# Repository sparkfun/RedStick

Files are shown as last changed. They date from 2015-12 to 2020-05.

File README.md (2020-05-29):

**NOTE:** *This product has been retired from our catalog. If you are looking for more up-to-date info, please check out some of these resources to see how other users are still hacking and improving on this product.*
* *[SparkFun Forum](https://forum.sparkfun.com/)*
* *[Comments Here on GitHub](https://github.com/sparkfun/RedStick/issues)*

SparkFun RedStick
========================================

SparkFun RedStick

[*SparkFun RedStick (DEV-13741)*](https://www.sparkfun.com/products/13741)

A 328p micro board with boost regulator that runs at 16MHz and has a built in boost regulator for battery usage.

Spawned from the BadgerStick promo.

Repository Contents
-------------------

* **/Documentation** - Data sheets, additional product information
* **/Hardware** - Eagle design files (.brd, .sch)
* **/Production** - Production panel files (.brd)
* **/Software** - Related software for the RedStick

Documentation
--------------
* **[LED Array Library](https://github.com/sparkfun/SparkFun_LED_Array_8x7_Arduino_Library)** - Arduino LED Array library for the RedStick.
* **[Hookup Guide](https://learn.sparkfun.com/tutorials/redstick-hookup-guide)** - Basic hookup guide for the RedStick.
* **[SparkFun Fritzing repo](https://github.com/sparkfun/Fritzing_Parts)** - Fritzing diagrams for SparkFun products.
* **[SparkFun 3D Model repo](https://github.com/sparkfun/3D_Models)** - 3D models of SparkFun products. 

Version History
---------------
* [V_1.0](https://github.com/sparkfun/RedStick/tree/V_1.0) - Product release version

License Information
-------------------

This product is _**open source**_! 

Please review the LICENSE.md file for license information. 

If you have any questions or concerns on licensing, please contact techsupport@sparkfun.com.

Distributed as-is; no warranty is given.

- Your friends at SparkFun.

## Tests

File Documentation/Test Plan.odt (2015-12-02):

# Functional Testing Plan

## Functional Things to Verify

- Does the serial pinout make sense?

## HW Things to Verify

- Power consumption
- Sweep input voltage from 1 to max 6 V with low load
- Sweep input voltage from 1 to max 6 V with large load (100mA)
- Measure efficiency and 5v voltage/ripple/sag
- Test that the battery port is protected.
- Test that the boost is protected from serial power
- I2C signal integrity – Test with known board
- SPI signal integrity – Test with known board
- Serial port signal integrity – Test with known board
- GPIO rise time and ringing with no load – record

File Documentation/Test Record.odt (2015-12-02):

# Functional Test Record – SparkFun RedStick

Marshall Taylor

11/30/2015

HW version v01

## Verifying Serial Pinout

Procedure:

(note: Products that have TTL: FTDI basics, serial 7 segment, pi wedge)

List SparkFun Products with TTL serial port:

- FTDI basic
- Serial 7 segment
- Pi Wedge
- Serial LCD
- GPS modules

Criteria:

Do modern and useful serial ports line up properly more often then not? Discuss

No real standard exists. TX and RX are together on a lot, with various organizations of power and ground. The FTDI is the closest thing to standard but has extra pins. Going with any old 4 pin pattern really. This one allows reverse without shorting powers, but does let TXI drive ground.

## Power Circuitry Tests

#### Low Load Test

Procedure:

- Power from battery input with fine voltage supply.
- Increase input voltage from 1V to 6V. Measure Vin/Iin, Vout/Iout, ripple

Criteria:

- Does regulator provide clean output between 2.0 V and 5.0 V?
- Is efficiency above 80% in this range? No
- Is ripple below 10% in this range? Yes
- Mark the switching frequency: About 5kHz
- Data:

Ripple generated at low load (Burpy)

#### 100mA Load Test

Procedure:

- Load 100mA total, add load to VCC pin
- Power from battery input with fine voltage supply.
- Increase input voltage from 1V to 6V. Measure Vin/Iin, Vout/Iout, ripple

Criteria:

- Does regulator provide clean output between 2.0 V and 5.0 V? Yes
- Is efficiency above 80% in this range? No
- Is ripple below 10% in this range? Yes
- Mark the switching frequency: Various (See below)
- Data:

Ripple generated at 100mA

#### 200mA Load Test

Procedure:

- Load 200mA total, add load to VCC pin
- Power from battery input with fine voltage supply.
- Increase input voltage from 1V to 6V. Measure Vin/Iin, Vout/Iout, ripple

Criteria:

- Does regulator provide clean output between 2.0 V and 5.0 V? Voltage sags below 3.0 V, 4.0 V output at 2.5 V input
- Is efficiency above 80% in this range? No
- Is ripple below 10% in this range? Yes
- Mark the switching frequency: Various (See below)
- Data:

#### All Power Test Graphs

#### Test the regulator's reverse flow

Procedure:

- Apply 5.0 V to the serial VCC port
- Switch between shorting and opening the USB connection (simulate reverse plug-in)

Criteria:

- The total current input should match the no-load consumption of the MPU +/- 5% Shorting the USB power lines had zero effect on current draw.

#### Test the battery protection from rogue VCC input

Procedure:

- Attach a 3.0 V battery and current meter to the battery input.
- Apply 5.0 V to the serial VCC port.

Criteria:

- The battery must not accept current. The battery consumed 0.00 A

#### Test the battery protection from USB input

Procedure:

- Attach a 3.0 V battery and current meter to the battery input
- Apply 5.0 V to the USB VCC port

Criteria:

- The battery must not accept current. The battery consumed 0.00 A

#### Extra test: Step loads

Procedure:

- Apply 2.5 V to the battery port
- Step loads between 0 and 100mA (total)

Criteria:

- Ringing should be minimal. 10 V for 40 ns
- Attach labeled scope captures.

38mA load switching in

75mA load switching in

75mA load switching out

95mA load switching in

95mA load switching out

#### Extra test: Reverse battery voltage

Procedure:

- Apply reverse voltage to battery terminals

Criteria:

- Must not crater. 0.00 A was consumed from the reverse voltage. RedStick operated normally afterwards.

## Set LED bias

Procedure:

- Measure red current at Vin = 2.0 V. 0.34mA
- Measure red current at Vin = 5.5 V. 0.36mA
- Measure green current at Vin = 2.0 V. 8.73mA
- Choose and set new resistors:
- Red: Use 4.7kOhm
- Green: Use 2.2kOhm for ~1.5mA of current

## Test I2C signal integrity

Procedure:

- Attach a I2C device and start communication
- Capture signals with a scope.

Criteria:

- Mark test device (AUT): 7segment display with 4.7kOhm pullups
- Are signals square and settled before clk edge?
- Clock should be clean
- Record scope capture

## Test SPI signal integrity

Procedure:

- Attach a SPI device through level shifter and start communication
- Capture signals with a scope between EUT and level shifter

Criteria:

- Mark test defice (AUT): BME280 with level shifter
- Are signals square and settled before clk edge?
- Clock should be clean
- Record scope capture

## Test serial TTL signal integrity

Procedure:

- Attach a serial device and start communication
- Capture signals with a scope.

Criteria:

- Mark test defice (AUT): FTDI loop at 115200 baud
- Are RX and TX typical?: Yes
- Record scope capture

TXO

RXI

## Test GPIO

Procedure:

- Set code to pulse each pin sequentially
- Capture signals with a scope.
- Look for out of order pulses ( > 1 pulse per pin13 cycle)
- Verify A0 – A7 by translating inputs to a PWM output and measuring

Criteria:

- Is each pin individually controllable? Yes
- Do any pins stick out as different from the others? No
- Do all analog inputs work and are stable? Yes
- Record scope capture of worst 2 pins. All pretty much the same

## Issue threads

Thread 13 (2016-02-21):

Incorrect part value

BrentWilkins, 2016-02-21:
The FTS31... Should be a FT231X...

ToniCorinne, 2016-03-07:
As this change will update the IC silk, leaving as-is until a revision is needed.

SFEMark, 2020-05-29:
Retired product. Closing issue.

bboyho, 2020-05-29:
In case anyone was wondering, this looks like it was just the part name in the schematic and it did not require changes to the silkscreen in the board file.

Closed 2020-05-29.

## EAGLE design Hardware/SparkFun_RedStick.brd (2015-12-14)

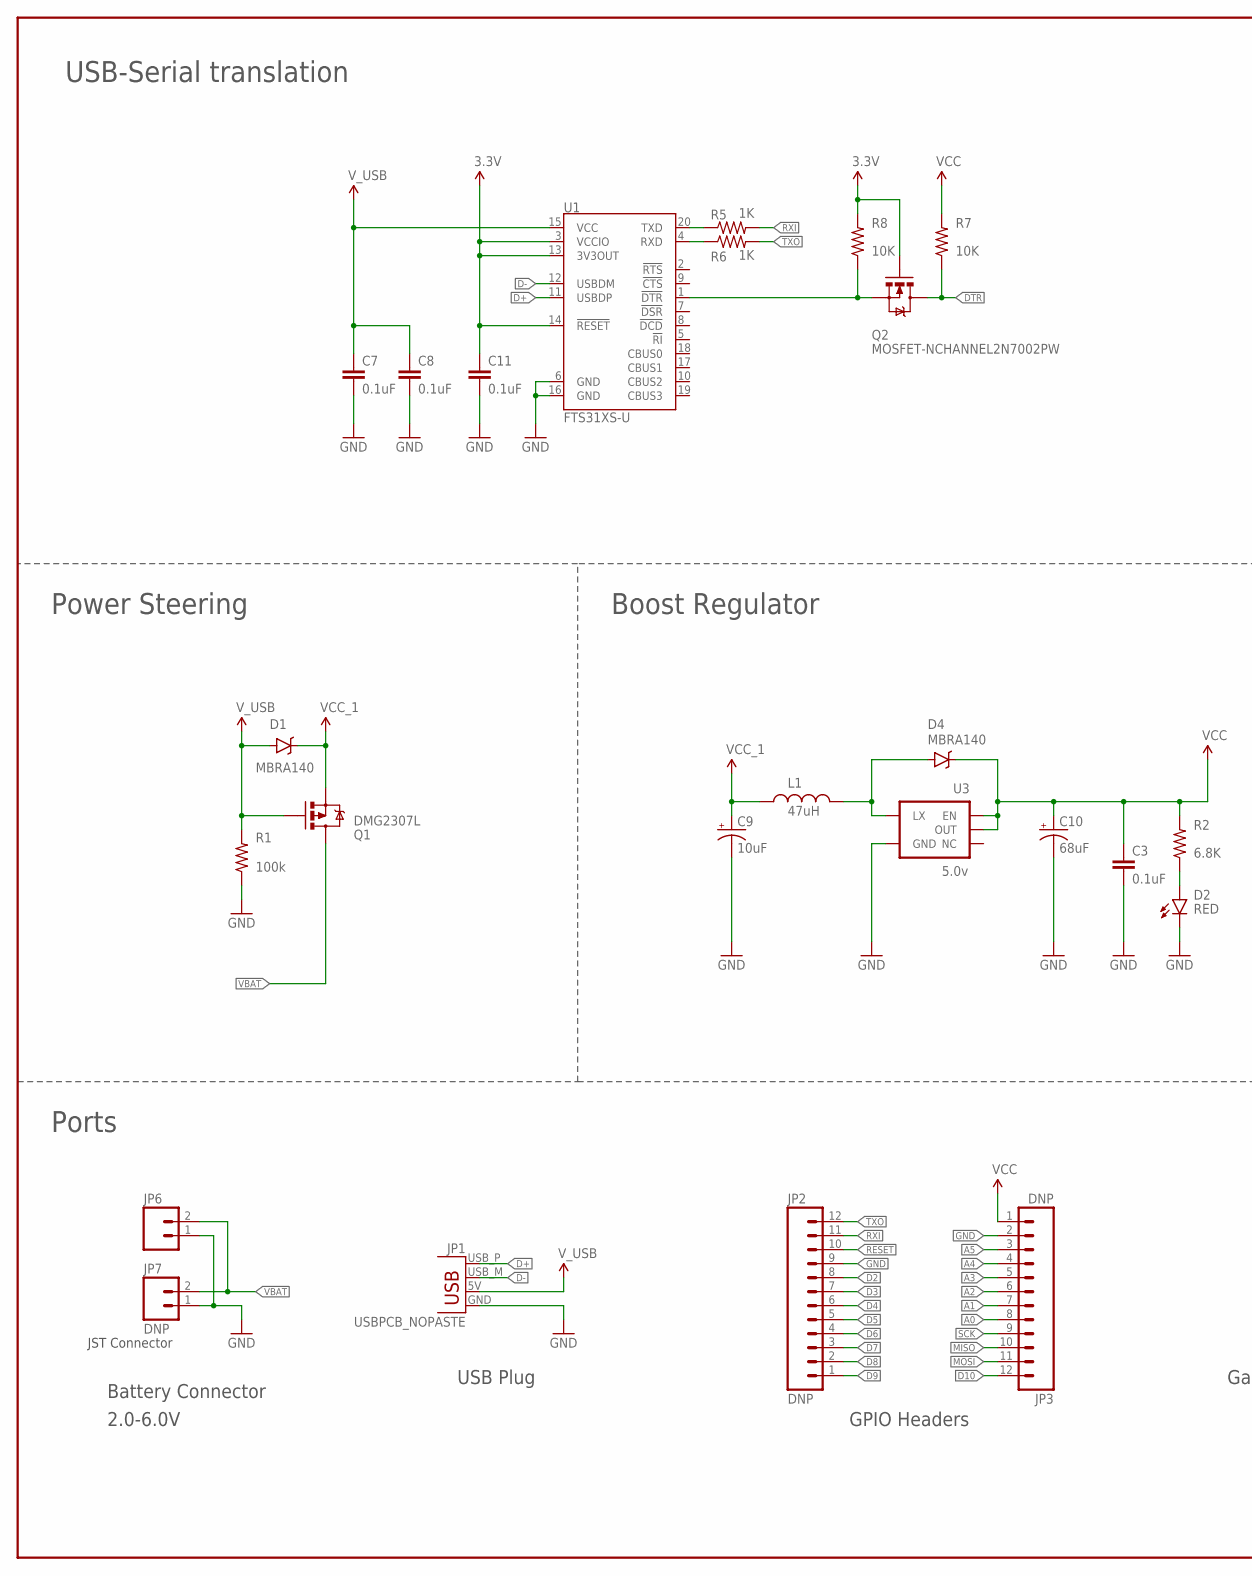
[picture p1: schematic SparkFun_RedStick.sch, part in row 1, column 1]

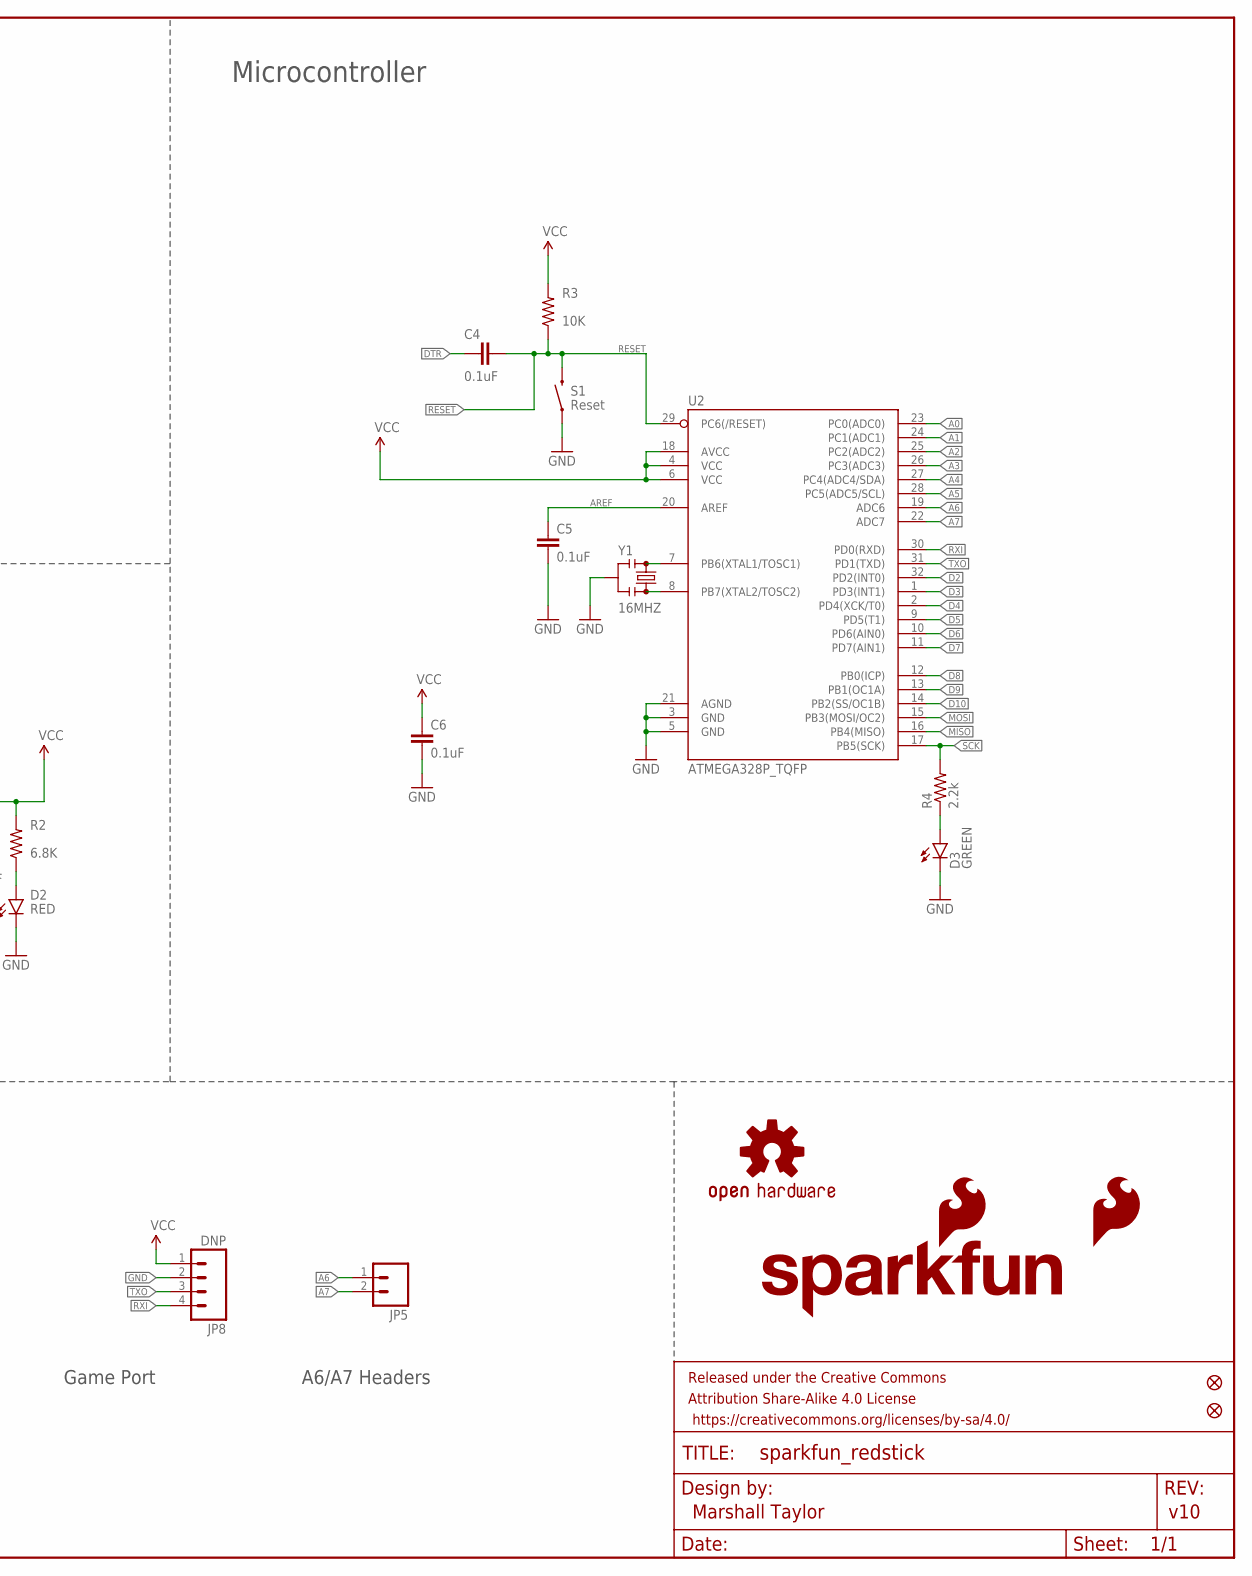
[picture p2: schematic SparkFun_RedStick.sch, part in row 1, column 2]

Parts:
C3, C4, C5, C6, C7, C8, C11: 0.1uF; 0603-CAP
C9: 10uF; EIA3216
C10: 68uF; EIA3528
D1, D4: MBRA140; SMA-DIODE
D2: RED; LED-0603
D3: GREEN; LED-0603
FID1, FID2: FIDUCIAL1X2; FIDUCIAL-1X2
FRAME2: FRAME-LEDGER; CREATIVE_COMMONS
JP1: USBPCB_NOPASTE; USB-A-PCB-NOPASTE
JP2, JP3: DNP; 1X12_NO_SILK
JP5, JP6: M021X02_NO_SILK; 1X02_NO_SILK
JP7: DNP; JST-2-PTH
JP8: DNP; 1X04_NO_SILK_ALL_ROUND
L1: 47uH; CR54
LOGO1: SFE_LOGO_FLAME.1_INCH; SFE_LOGO_FLAME_.1
LOGO2: OSHW-LOGOS; OSHW-LOGO-S
Q1: DMG2307L; SOT23-3
Q2: MOSFET-NCHANNEL2N7002PW; SOT323
R1: 100k; 0603-RES
R2: 6.8K; 0603-RES
R3, R7, R8: 10K; 0603-RES
R4: 2.2k; 0603-RES
R5, R6: 1K; 0603-RES
S1: SWITCH-MOMENTARY-2SMD-REDUNDANT; TACTILE-SWITCH-SMD
U1: FTS31XS-U; SSOP20_L
U2: ATMEGA328P_TQFP; TQFP32-08
U3: 5.0v; SOT23-5
U$1: SFE_LOGO_NAME_FLAME.1_INCH; SFE_LOGO_NAME_FLAME_.1
Y1: 16MHZ; RESONATOR-SMD

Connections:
3.3V: C11.1, Q2.1 (G), R8.2, U1.3 (VCCIO), U1.13 (3V3OUT), U1.14 (!RESET)
A0: JP3.8, U2.23 (PC0(ADC0))
A1: JP3.7, U2.24 (PC1(ADC1))
A2: JP3.6, U2.25 (PC2(ADC2))
A3: JP3.5, U2.26 (PC3(ADC3))
A4: JP3.4, U2.27 (PC4(ADC4/SDA))
A5: JP3.3, U2.28 (PC5(ADC5/SCL))
A6: JP5.1, U2.19 (ADC6)
A7: JP5.2, U2.22 (ADC7)
AREF: C5.1, U2.20 (AREF)
D2: JP2.8, U2.32 (PD2(INT0))
D3: JP2.7, U2.1 (PD3(INT1))
D4: JP2.6, U2.2 (PD4(XCK/T0))
D5: JP2.5, U2.9 (PD5(T1))
D6: JP2.4, U2.10 (PD6(AIN0))
D7: JP2.3, U2.11 (PD7(AIN1))
D8: JP2.2, U2.12 (PB0(ICP))
D9: JP2.1, U2.13 (PB1(OC1A))
D10: JP3.12, U2.14 (PB2(SS/OC1B))
D+: JP1.USB_P (D+), U1.11 (USBDP)
D-: JP1.USB_M (D-), U1.12 (USBDM)
DTR: C4.1, Q2.3 (D), R7.1
GND: C3.2, C5.2, C6.2, C7.2, C8.2, C9.C (-), C10.C (-), C11.2, D2.C, D3.C, JP1.GND, JP2.9, JP3.2, JP6.1, JP7.1, JP8.2, R1.1, S1.1, S1.2 (1), U1.6 (GND), U1.16 (GND), U2.3 (GND), U2.5 (GND), U2.21 (AGND), U3.4 (GND), Y1.2
MISO: JP3.10, U2.16 (PB4(MISO))
MOSI: JP3.11, U2.15 (PB3(MOSI/OC2))
unnamed: D3.A, R4.1
unnamed: R5.1, U1.20 (TXD)
unnamed: D2.A, R2.1
unnamed: U2.7 (PB6(XTAL1/TOSC1)), Y1.1
unnamed: U2.8 (PB7(XTAL2/TOSC2)), Y1.3
unnamed: R6.1, U1.4 (RXD)
unnamed: D4.A, L1.P$2 (2), U3.5 (LX)
unnamed: Q2.2 (S), R8.1, U1.1 (!DTR)
RESET: C4.2, JP2.10, R3.1, S1.3 (2), S1.4 (2), U2.29 (PC6(/RESET))
RXI: JP2.11, JP8.4, R5.2, U2.30 (PD0(RXD))
SCK: JP3.9, R4.2, U2.17 (PB5(SCK))
TXO: JP2.12, JP8.3, R6.2, U2.31 (PD1(TXD))
VBAT: JP6.2, JP7.2, Q1.3 (D)
VCC: C3.1, C6.1, C10.A (+), D4.C, JP3.1, JP8.1, R2.2, R3.2, R7.2, U2.4 (VCC), U2.6 (VCC), U2.18 (AVCC), U3.1 (EN), U3.2 (OUT)
VCC_1: C9.A (+), D1.C, L1.P$1 (1), Q1.2 (S)
V_USB: C7.1, C8.1, D1.A, JP1.5V (VBUS), Q1.1 (G), R1.2, U1.15 (VCC)

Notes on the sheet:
USB Plug
GPIO Headers
A6/A7 Headers
Game Port
Battery Connector
JST Connector
Ports
Power Steering
Boost Regulator
USB-Serial translation
Microcontroller
v10
Marshall Taylor
2.0-6.0V

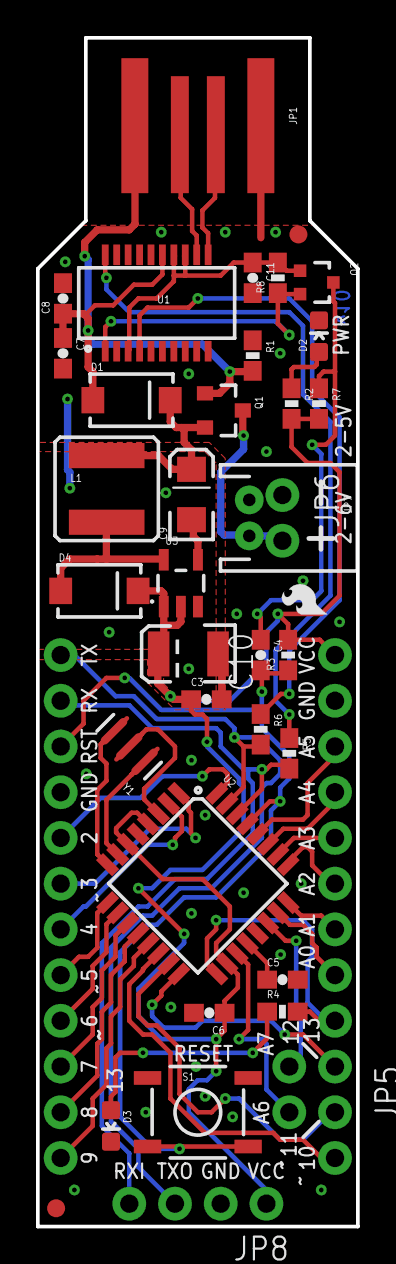
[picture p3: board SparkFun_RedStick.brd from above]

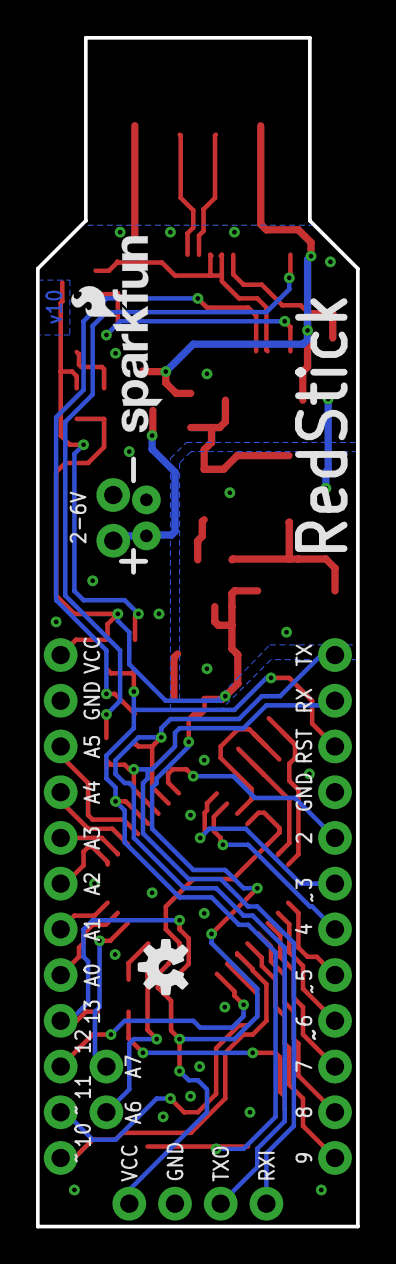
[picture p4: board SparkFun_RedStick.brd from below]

Board: 2 copper layers, 17.8 x 66.0 mm, 42 parts (2 on the bottom side), 41 nets.

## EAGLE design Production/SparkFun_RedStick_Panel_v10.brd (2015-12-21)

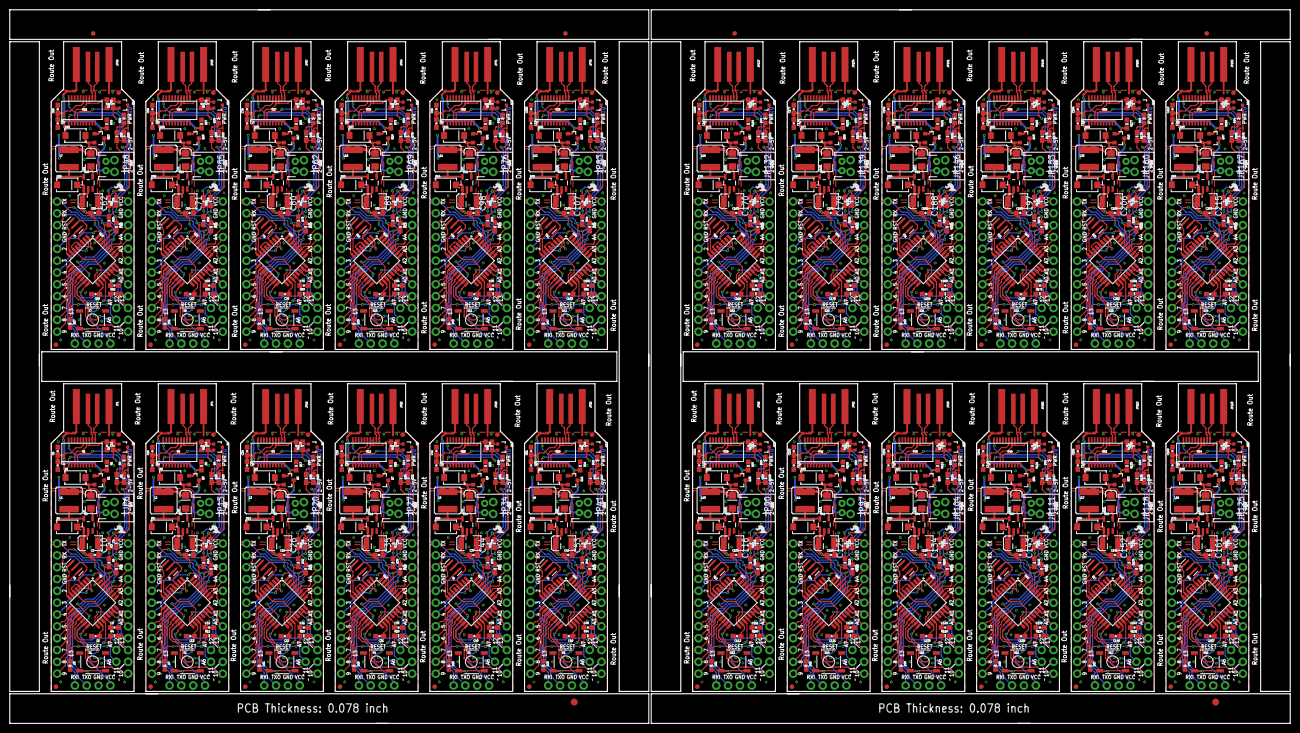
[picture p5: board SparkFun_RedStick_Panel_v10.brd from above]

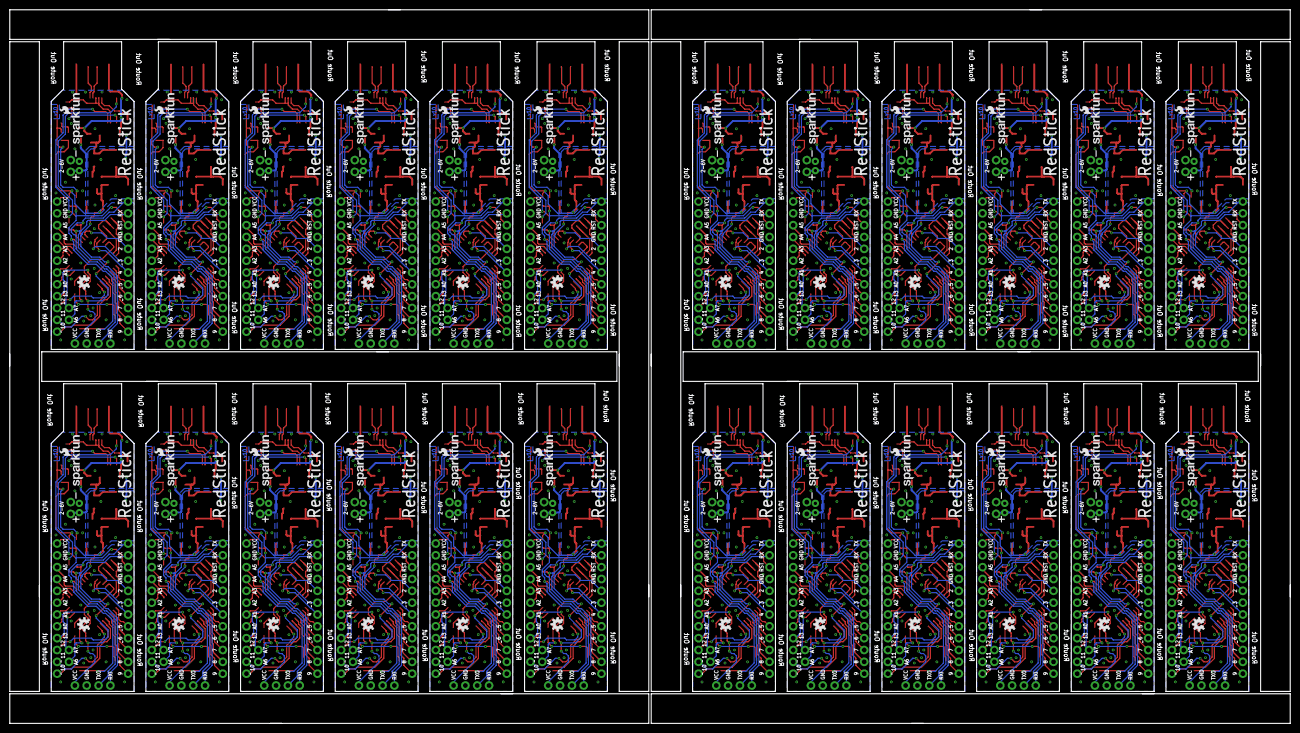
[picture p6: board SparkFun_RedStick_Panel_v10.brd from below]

Board: 2 copper layers, 274.8 x 153.2 mm, 990 parts (48 on the bottom side), 984 nets.

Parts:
C1, C2, C3, C4, C5, C6, C7, C8, C11, C12, C13, C14, C15, C18, C19, C20, C21, C22, C23, C24, C27, C28, C29, C30, C31, C32, C33, C36, C37, C38, C39, C40, C41, C42, C45, C46, C47, C48, C49, C50, C51, C54, C55, C56, C57, C58, C59, C60, C63, C64, C65, C66, C67, C68, C69, C72, C73, C74, C75, C76, C77, C78, C81, C82, C83, C84, C85, C86, C87, C90, C91, C92, C93, C94, C95, C96, C99, C100, C101, C102, C103, C104, C105, C108, C109, C110, C111, C112, C113, C114, C117, C118, C119, C120, C121, C122, C123, C126, C127, C128, C129, C130, C131, C132, C135, C136, C137, C138, C139, C140, C141, C144, C145, C146, C147, C148, C149, C150, C153, C154, C155, C156, C157, C158, C159, C162, C163, C164, C165, C166, C167, C168, C171, C172, C173, C174, C175, C176, C177, C180, C181, C182, C183, C184, C185, C186, C189, C190, C191, C192, C193, C194, C195, C198, C199, C200, C201, C202, C203, C204, C207, C208, C209, C210, C211, C212, C213, C216: 0.1uF; 0603-CAP
C9, C16, C25, C34, C43, C52, C61, C70, C79, C88, C97, C106, C115, C124, C133, C142, C151, C160, C169, C178, C187, C196, C205, C214: 10uF; EIA3216
C10, C17, C26, C35, C44, C53, C62, C71, C80, C89, C98, C107, C116, C125, C134, C143, C152, C161, C170, C179, C188, C197, C206, C215: 68uF; EIA3528
D1, D4, D5, D8, D9, D12, D13, D16, D17, D20, D21, D24, D25, D28, D29, D32, D33, D36, D37, D40, D41, D44, D45, D48, D49, D52, D53, D56, D57, D60, D61, D64, D65, D68, D69, D72, D73, D76, D77, D80, D81, D84, D85, D88, D89, D92, D93, D96: MBRA140; SMA-DIODE
D2, D6, D10, D14, D18, D22, D26, D30, D34, D38, D42, D46, D50, D54, D58, D62, D66, D70, D74, D78, D82, D86, D90, D94: RED; LED-0603
D3, D7, D11, D15, D19, D23, D27, D31, D35, D39, D43, D47, D51, D55, D59, D63, D67, D71, D75, D79, D83, D87, D91, D95: GREEN; LED-0603
E$1, E$4: FIDUCIAL-1.5X3
E$2, E$3, E$5, E$6: FIDUCIAL-1X2
FID1, FID2, FID3, FID4, FID5, FID6, FID7, FID8, FID9, FID10, FID11, FID12, FID13, FID14, FID15, FID16, FID17, FID18, FID19, FID20, FID21, FID22, FID23, FID24, FID25, FID26, FID27, FID28, FID29, FID30, FID31, FID32, FID33, FID34, FID35, FID36, FID37, FID38, FID39, FID40, FID41, FID42, FID43, FID44, FID45, FID46, FID47, FID48: FIDUCIAL1X2; FIDUCIAL-1X2
JP1, JP4, JP15, JP22, JP29, JP36, JP43, JP50, JP57, JP64, JP71, JP78, JP85, JP92, JP99, JP106, JP113, JP120, JP127, JP134, JP141, JP148, JP155, JP162: USBPCB_NOPASTE; USB-A-PCB-NOPASTE
JP2, JP3, JP10, JP11, JP17, JP18, JP24, JP25, JP31, JP32, JP38, JP39, JP45, JP46, JP52, JP53, JP59, JP60, JP66, JP67, JP73, JP74, JP80, JP81, JP87, JP88, JP94, JP95, JP101, JP102, JP108, JP109, JP115, JP116, JP122, JP123, JP129, JP130, JP136, JP137, JP143, JP144, JP150, JP151, JP157, JP158, JP164, JP165: DNP; 1X12_NO_SILK
JP5, JP6, JP9, JP13, JP16, JP20, JP23, JP27, JP30, JP34, JP37, JP41, JP44, JP48, JP51, JP55, JP58, JP62, JP65, JP69, JP72, JP76, JP79, JP83, JP86, JP90, JP93, JP97, JP100, JP104, JP107, JP111, JP114, JP118, JP121, JP125, JP128, JP132, JP135, JP139, JP142, JP146, JP149, JP153, JP156, JP160, JP163, JP167: M021X02_NO_SILK; 1X02_NO_SILK
JP7, JP12, JP19, JP26, JP33, JP40, JP47, JP54, JP61, JP68, JP75, JP82, JP89, JP96, JP103, JP110, JP117, JP124, JP131, JP138, JP145, JP152, JP159, JP166: DNP; JST-2-PTH
JP8, JP14, JP21, JP28, JP35, JP42, JP49, JP56, JP63, JP70, JP77, JP84, JP91, JP98, JP105, JP112, JP119, JP126, JP133, JP140, JP147, JP154, JP161, JP168: DNP; 1X04_NO_SILK_ALL_ROUND
L1, L2, L3, L4, L5, L6, L7, L8, L9, L10, L11, L12, L13, L14, L15, L16, L17, L18, L19, L20, L21, L22, L23, L24: 47uH; CR54
LOGO1, LOGO3, LOGO5, LOGO7, LOGO9, LOGO11, LOGO13, LOGO15, LOGO17, LOGO19, LOGO21, LOGO23, LOGO25, LOGO27, LOGO29, LOGO31, LOGO33, LOGO35, LOGO37, LOGO39, LOGO41, LOGO43, LOGO45, LOGO47: SFE_LOGO_FLAME.1_INCH; SFE_LOGO_FLAME_.1
LOGO2, LOGO4, LOGO6, LOGO8, LOGO10, LOGO12, LOGO14, LOGO16, LOGO18, LOGO20, LOGO22, LOGO24, LOGO26, LOGO28, LOGO30, LOGO32, LOGO34, LOGO36, LOGO38, LOGO40, LOGO42, LOGO44, LOGO46, LOGO48: OSHW-LOGOS; OSHW-LOGO-S
Q1, Q3, Q5, Q7, Q9, Q11, Q13, Q15, Q17, Q19, Q21, Q23, Q25, Q27, Q29, Q31, Q33, Q35, Q37, Q39, Q41, Q43, Q45, Q47: DMG2307L; SOT23-3
Q2, Q4, Q6, Q8, Q10, Q12, Q14, Q16, Q18, Q20, Q22, Q24, Q26, Q28, Q30, Q32, Q34, Q36, Q38, Q40, Q42, Q44, Q46, Q48: MOSFET-NCHANNEL2N7002PW; SOT323
R1, R9, R17, R25, R33, R41, R49, R57, R65, R73, R81, R89, R97, R105, R113, R121, R129, R137, R145, R153, R161, R169, R177, R185: 100k; 0603-RES
R2, R10, R18, R26, R34, R42, R50, R58, R66, R74, R82, R90, R98, R106, R114, R122, R130, R138, R146, R154, R162, R170, R178, R186: 6.8K; 0603-RES
R3, R7, R8, R11, R15, R16, R19, R23, R24, R27, R31, R32, R35, R39, R40, R43, R47, R48, R51, R55, R56, R59, R63, R64, R67, R71, R72, R75, R79, R80, R83, R87, R88, R91, R95, R96, R99, R103, R104, R107, R111, R112, R115, R119, R120, R123, R127, R128, R131, R135, R136, R139, R143, R144, R147, R151, R152, R155, R159, R160, R163, R167, R168, R171, R175, R176, R179, R183, R184, R187, R191, R192: 10K; 0603-RES
R4, R12, R20, R28, R36, R44, R52, R60, R68, R76, R84, R92, R100, R108, R116, R124, R132, R140, R148, R156, R164, R172, R180, R188: 2.2k; 0603-RES
R5, R6, R13, R14, R21, R22, R29, R30, R37, R38, R45, R46, R53, R54, R61, R62, R69, R70, R77, R78, R85, R86, R93, R94, R101, R102, R109, R110, R117, R118, R125, R126, R133, R134, R141, R142, R149, R150, R157, R158, R165, R166, R173, R174, R181, R182, R189, R190: 1K; 0603-RES
S1, S2, S3, S4, S5, S6, S7, S8, S9, S10, S11, S12, S13, S14, S15, S16, S17, S18, S19, S20, S21, S22, S23, S24: SWITCH-MOMENTARY-2SMD-REDUNDANT; TACTILE-SWITCH-SMD
U1, U6, U9, U12, U15, U18, U21, U24, U27, U30, U33, U36, U39, U42, U45, U48, U51, U54, U57, U60, U63, U66, U69, U72: FTS31XS-U; SSOP20_L
U2, U4, U7, U10, U13, U16, U19, U22, U25, U28, U31, U34, U37, U40, U43, U46, U49, U52, U55, U58, U61, U64, U67, U70: ATMEGA328P_TQFP; TQFP32-08
U3, U5, U8, U11, U14, U17, U20, U23, U26, U29, U32, U35, U38, U41, U44, U47, U50, U53, U56, U59, U62, U65, U68, U71: 5.0v; SOT23-5
U$1, U$2, U$3, U$4, U$5, U$6, U$7, U$8, U$9, U$10, U$11, U$12, U$13, U$14, U$15, U$16, U$17, U$18, U$19, U$20, U$21, U$22, U$23, U$24: SFE_LOGO_NAME_FLAME.1_INCH; SFE_LOGO_NAME_FLAME_.1
Y1, Y2, Y3, Y4, Y5, Y6, Y7, Y8, Y9, Y10, Y11, Y12, Y13, Y14, Y15, Y16, Y17, Y18, Y19, Y20, Y21, Y22, Y23, Y24: 16MHZ; RESONATOR-SMD

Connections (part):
3.3V: C11.1, Q2.1, R8.2, U1.3, U1.13, U1.14
3.3V1: C18.1, Q4.1, R16.2, U6.3, U6.13, U6.14
3.3V2: C27.1, Q6.1, R24.2, U9.3, U9.13, U9.14
3.3V3: C36.1, Q8.1, R32.2, U12.3, U12.13, U12.14
3.3V4: C45.1, Q10.1, R40.2, U15.3, U15.13, U15.14
3.3V5: C54.1, Q12.1, R48.2, U18.3, U18.13, U18.14
3.3V6: C63.1, Q14.1, R56.2, U21.3, U21.13, U21.14
3.3V7: C72.1, Q16.1, R64.2, U24.3, U24.13, U24.14
3.3V8: C81.1, Q18.1, R72.2, U27.3, U27.13, U27.14
3.3V9: C90.1, Q20.1, R80.2, U30.3, U30.13, U30.14
3.3V10: C99.1, Q22.1, R88.2, U33.3, U33.13, U33.14
3.3V11: C108.1, Q24.1, R96.2, U36.3, U36.13, U36.14
3.3V12: C117.1, Q26.1, R104.2, U39.3, U39.13, U39.14
3.3V13: C126.1, Q28.1, R112.2, U42.3, U42.13, U42.14
3.3V14: C135.1, Q30.1, R120.2, U45.3, U45.13, U45.14
3.3V15: C144.1, Q32.1, R128.2, U48.3, U48.13, U48.14
3.3V16: C153.1, Q34.1, R136.2, U51.3, U51.13, U51.14
3.3V17: C162.1, Q36.1, R144.2, U54.3, U54.13, U54.14
3.3V18: C171.1, Q38.1, R152.2, U57.3, U57.13, U57.14
3.3V19: C180.1, Q40.1, R160.2, U60.3, U60.13, U60.14
3.3V20: C189.1, Q42.1, R168.2, U63.3, U63.13, U63.14
3.3V21: C198.1, Q44.1, R176.2, U66.3, U66.13, U66.14
3.3V22: C207.1, Q46.1, R184.2, U69.3, U69.13, U69.14
3.3V23: C216.1, Q48.1, R192.2, U72.3, U72.13, U72.14
A0: JP3.8, U2.23
A1: JP3.7, U2.24
A2: JP3.6, U2.25
A3: JP3.5, U2.26
A4: JP3.4, U2.27
A5: JP3.3, U2.28
A6: JP5.1, U2.19
A7: JP5.2, U2.22
A8: JP10.8, U4.23
A9: JP10.7, U4.24
A10: JP10.6, U4.25
A11: JP10.5, U4.26
A12: JP10.4, U4.27
A13: JP10.3, U4.28
A14: JP9.1, U4.19
A15: JP9.2, U4.22
A16: JP17.8, U7.23
A17: JP17.7, U7.24
A18: JP17.6, U7.25
A19: JP17.5, U7.26
A20: JP17.4, U7.27
A21: JP17.3, U7.28
A22: JP16.1, U7.19
A23: JP16.2, U7.22
A24: JP24.8, U10.23
A25: JP24.7, U10.24
A26: JP24.6, U10.25
A27: JP24.5, U10.26
A28: JP24.4, U10.27
A29: JP24.3, U10.28
A30: JP23.1, U10.19
A31: JP23.2, U10.22
A32: JP31.8, U13.23
A33: JP31.7, U13.24
A34: JP31.6, U13.25
A35: JP31.5, U13.26
A36: JP31.4, U13.27
A37: JP31.3, U13.28
A38: JP30.1, U13.19
A39: JP30.2, U13.22
A40: JP38.8, U16.23
A41: JP38.7, U16.24
A42: JP38.6, U16.25
A43: JP38.5, U16.26
A44: JP38.4, U16.27
A45: JP38.3, U16.28
A46: JP37.1, U16.19
A47: JP37.2, U16.22
A48: JP45.8, U19.23
A49: JP45.7, U19.24
A50: JP45.6, U19.25
A51: JP45.5, U19.26
A52: JP45.4, U19.27
A53: JP45.3, U19.28
A54: JP44.1, U19.19
A55: JP44.2, U19.22
A56: JP52.8, U22.23
A57: JP52.7, U22.24
A58: JP52.6, U22.25
A59: JP52.5, U22.26
A60: JP52.4, U22.27
A61: JP52.3, U22.28
A62: JP51.1, U22.19
A63: JP51.2, U22.22
A64: JP59.8, U25.23
A65: JP59.7, U25.24
A66: JP59.6, U25.25
A67: JP59.5, U25.26
A68: JP59.4, U25.27
A69: JP59.3, U25.28
A70: JP58.1, U25.19
A71: JP58.2, U25.22
A72: JP66.8, U28.23
A73: JP66.7, U28.24
A74: JP66.6, U28.25
A75: JP66.5, U28.26
A76: JP66.4, U28.27
A77: JP66.3, U28.28
A78: JP65.1, U28.19
A79: JP65.2, U28.22
A80: JP73.8, U31.23
A81: JP73.7, U31.24
A82: JP73.6, U31.25
A83: JP73.5, U31.26
A84: JP73.4, U31.27
A85: JP73.3, U31.28
A86: JP72.1, U31.19
A87: JP72.2, U31.22
A88: JP80.8, U34.23
A89: JP80.7, U34.24
A90: JP80.6, U34.25
A91: JP80.5, U34.26
A92: JP80.4, U34.27
A93: JP80.3, U34.28
A94: JP79.1, U34.19
A95: JP79.2, U34.22
A96: JP87.8, U37.23
A97: JP87.7, U37.24
A98: JP87.6, U37.25
A99: JP87.5, U37.26
A100: JP87.4, U37.27
A101: JP87.3, U37.28
A102: JP86.1, U37.19
A103: JP86.2, U37.22
A104: JP94.8, U40.23
A105: JP94.7, U40.24
A106: JP94.6, U40.25
A107: JP94.5, U40.26
A108: JP94.4, U40.27
A109: JP94.3, U40.28
A110: JP93.1, U40.19
A111: JP93.2, U40.22
A112: JP101.8, U43.23
A113: JP101.7, U43.24
A114: JP101.6, U43.25
A115: JP101.5, U43.26
A116: JP101.4, U43.27
A117: JP101.3, U43.28
A118: JP100.1, U43.19
A119: JP100.2, U43.22
A120: JP108.8, U46.23
A121: JP108.7, U46.24
A122: JP108.6, U46.25
A123: JP108.5, U46.26
A124: JP108.4, U46.27
A125: JP108.3, U46.28
A126: JP107.1, U46.19
A127: JP107.2, U46.22
A128: JP115.8, U49.23
A129: JP115.7, U49.24
A130: JP115.6, U49.25
A131: JP115.5, U49.26
A132: JP115.4, U49.27
A133: JP115.3, U49.28
A134: JP114.1, U49.19
A135: JP114.2, U49.22
A136: JP122.8, U52.23
A137: JP122.7, U52.24
A138: JP122.6, U52.25
A139: JP122.5, U52.26
A140: JP122.4, U52.27
A141: JP122.3, U52.28
A142: JP121.1, U52.19
A143: JP121.2, U52.22
A144: JP129.8, U55.23
A145: JP129.7, U55.24
A146: JP129.6, U55.25
A147: JP129.5, U55.26
A148: JP129.4, U55.27
A149: JP129.3, U55.28
A150: JP128.1, U55.19
A151: JP128.2, U55.22
A152: JP136.8, U58.23
A153: JP136.7, U58.24
A154: JP136.6, U58.25
A155: JP136.5, U58.26
A156: JP136.4, U58.27
A157: JP136.3, U58.28
A158: JP135.1, U58.19
A159: JP135.2, U58.22
A160: JP143.8, U61.23
A161: JP143.7, U61.24
A162: JP143.6, U61.25
A163: JP143.5, U61.26
A164: JP143.4, U61.27
A165: JP143.3, U61.28
A166: JP142.1, U61.19
A167: JP142.2, U61.22
A168: JP150.8, U64.23
A169: JP150.7, U64.24
A170: JP150.6, U64.25
A171: JP150.5, U64.26
A172: JP150.4, U64.27
A173: JP150.3, U64.28
A174: JP149.1, U64.19
A175: JP149.2, U64.22
A176: JP157.8, U67.23
A177: JP157.7, U67.24
A178: JP157.6, U67.25
A179: JP157.5, U67.26
A180: JP157.4, U67.27
A181: JP157.3, U67.28
A182: JP156.1, U67.19
A183: JP156.2, U67.22
A184: JP164.8, U70.23
A185: JP164.7, U70.24
A186: JP164.6, U70.25
A187: JP164.5, U70.26
A188: JP164.4, U70.27
A189: JP164.3, U70.28
A190: JP163.1, U70.19
A191: JP163.2, U70.22
AREF: C5.1, U2.20
AREF1: C12.1, U4.20
AREF2: C21.1, U7.20
AREF3: C30.1, U10.20
AREF4: C39.1, U13.20
AREF5: C48.1, U16.20
AREF6: C57.1, U19.20
AREF7: C66.1, U22.20
AREF8: C75.1, U25.20
AREF9: C84.1, U28.20
AREF10: C93.1, U31.20
AREF11: C102.1, U34.20
AREF12: C111.1, U37.20
AREF13: C120.1, U40.20
AREF14: C129.1, U43.20
AREF15: C138.1, U46.20
AREF16: C147.1, U49.20
AREF17: C156.1, U52.20
AREF18: C165.1, U55.20
AREF19: C174.1, U58.20
AREF20: C183.1, U61.20
AREF21: C192.1, U64.20
AREF22: C201.1, U67.20
AREF23: C210.1, U70.20
D1: JP11.8, U4.32
D2: JP2.8, U2.32
D3: JP2.7, U2.1
D4: JP2.6, U2.2
D5: JP2.5, U2.9
D6: JP2.4, U2.10
D7: JP2.3, U2.11
D8: JP2.2, U2.12
D9: JP2.1, U2.13
D10: JP3.12, U2.14
D11: JP11.7, U4.1
D12: JP11.6, U4.2
D13: JP11.5, U4.9
D14: JP11.4, U4.10
D15: JP11.3, U4.11
D16: JP11.2, U4.12
D17: JP11.1, U4.13
D18: JP10.12, U4.14
D19: JP18.8, U7.32
D20: JP18.7, U7.1
D21: JP18.6, U7.2
D22: JP18.5, U7.9
D23: JP18.4, U7.10
D24: JP18.3, U7.11
D25: JP18.2, U7.12
D26: JP18.1, U7.13
D27: JP17.12, U7.14
D28: JP25.8, U10.32
D29: JP25.7, U10.1
D30: JP25.6, U10.2
D31: JP25.5, U10.9
D32: JP25.4, U10.10
D33: JP25.3, U10.11
D34: JP25.2, U10.12
D35: JP25.1, U10.13
D36: JP24.12, U10.14
D37: JP32.8, U13.32
D38: JP32.7, U13.1
D39: JP32.6, U13.2
D40: JP32.5, U13.9
D41: JP32.4, U13.10
D42: JP32.3, U13.11
D43: JP32.2, U13.12
D44: JP32.1, U13.13
D45: JP31.12, U13.14
D46: JP39.8, U16.32
D47: JP39.7, U16.1
D48: JP39.6, U16.2
D49: JP39.5, U16.9
D50: JP39.4, U16.10
D51: JP39.3, U16.11
D52: JP39.2, U16.12
D53: JP39.1, U16.13
D54: JP38.12, U16.14
D55: JP46.8, U19.32
D56: JP46.7, U19.1
D57: JP46.6, U19.2
D58: JP46.5, U19.9
D59: JP46.4, U19.10
D60: JP46.3, U19.11
D61: JP46.2, U19.12
D62: JP46.1, U19.13
D63: JP45.12, U19.14
D64: JP53.8, U22.32
D65: JP53.7, U22.1
D66: JP53.6, U22.2
D67: JP53.5, U22.9
D68: JP53.4, U22.10
D69: JP53.3, U22.11
D70: JP53.2, U22.12
D71: JP53.1, U22.13
D72: JP52.12, U22.14
D73: JP60.8, U25.32
D74: JP60.7, U25.1
D75: JP60.6, U25.2
D76: JP60.5, U25.9
D77: JP60.4, U25.10
D78: JP60.3, U25.11
D79: JP60.2, U25.12
D80: JP60.1, U25.13
D81: JP59.12, U25.14
D82: JP67.8, U28.32
D83: JP67.7, U28.1
D84: JP67.6, U28.2
D85: JP67.5, U28.9
D86: JP67.4, U28.10
D87: JP67.3, U28.11
D88: JP67.2, U28.12
D89: JP67.1, U28.13
D90: JP66.12, U28.14
D91: JP74.8, U31.32
D92: JP74.7, U31.1
D93: JP74.6, U31.2
D94: JP74.5, U31.9
D95: JP74.4, U31.10
D96: JP74.3, U31.11
D97: JP74.2, U31.12
D98: JP74.1, U31.13
D99: JP73.12, U31.14
D100: JP81.8, U34.32
D101: JP81.7, U34.1
D102: JP81.6, U34.2
D103: JP81.5, U34.9
D104: JP81.4, U34.10
D105: JP81.3, U34.11
D106: JP81.2, U34.12
D107: JP81.1, U34.13
D108: JP80.12, U34.14
D109: JP88.8, U37.32
D110: JP88.7, U37.1
D111: JP88.6, U37.2
D112: JP88.5, U37.9
D113: JP88.4, U37.10
D114: JP88.3, U37.11
D115: JP88.2, U37.12
D116: JP88.1, U37.13
D117: JP87.12, U37.14
D118: JP95.8, U40.32
D119: JP95.7, U40.1
D120: JP95.6, U40.2
D121: JP95.5, U40.9
D122: JP95.4, U40.10
D123: JP95.3, U40.11
D124: JP95.2, U40.12
D125: JP95.1, U40.13
D126: JP94.12, U40.14
D127: JP102.8, U43.32
D128: JP102.7, U43.1
D129: JP102.6, U43.2
D130: JP102.5, U43.9
D131: JP102.4, U43.10
D132: JP102.3, U43.11
D133: JP102.2, U43.12
D134: JP102.1, U43.13
D135: JP101.12, U43.14
D136: JP109.8, U46.32
D137: JP109.7, U46.1
D138: JP109.6, U46.2
D139: JP109.5, U46.9
D140: JP109.4, U46.10
D141: JP109.3, U46.11
D142: JP109.2, U46.12
D143: JP109.1, U46.13
D144: JP108.12, U46.14
D145: JP116.8, U49.32
D146: JP116.7, U49.1
D147: JP116.6, U49.2
D148: JP116.5, U49.9
D149: JP116.4, U49.10
D150: JP116.3, U49.11
D151: JP116.2, U49.12
D152: JP116.1, U49.13
D153: JP115.12, U49.14
D154: JP123.8, U52.32
D155: JP123.7, U52.1
D156: JP123.6, U52.2
D157: JP123.5, U52.9
D158: JP123.4, U52.10
D159: JP123.3, U52.11
D160: JP123.2, U52.12
D161: JP123.1, U52.13
D162: JP122.12, U52.14
D163: JP130.8, U55.32
D164: JP130.7, U55.1
D165: JP130.6, U55.2
D166: JP130.5, U55.9
D167: JP130.4, U55.10
D168: JP130.3, U55.11
D169: JP130.2, U55.12
D170: JP130.1, U55.13
D171: JP129.12, U55.14
D172: JP137.8, U58.32
D173: JP137.7, U58.1
D174: JP137.6, U58.2
D175: JP137.5, U58.9
D176: JP137.4, U58.10
D177: JP137.3, U58.11
D178: JP137.2, U58.12
D179: JP137.1, U58.13
D180: JP136.12, U58.14
D181: JP144.8, U61.32
D182: JP144.7, U61.1
D183: JP144.6, U61.2
D184: JP144.5, U61.9
D185: JP144.4, U61.10
D186: JP144.3, U61.11
D187: JP144.2, U61.12
D188: JP144.1, U61.13
D189: JP143.12, U61.14
D190: JP151.8, U64.32
D191: JP151.7, U64.1
D192: JP151.6, U64.2
D193: JP151.5, U64.9
D194: JP151.4, U64.10
D195: JP151.3, U64.11
D196: JP151.2, U64.12
D197: JP151.1, U64.13
D198: JP150.12, U64.14
D199: JP158.8, U67.32
D200: JP158.7, U67.1
D201: JP158.6, U67.2
D202: JP158.5, U67.9
D203: JP158.4, U67.10
D204: JP158.3, U67.11
D205: JP158.2, U67.12
D206: JP158.1, U67.13
D207: JP157.12, U67.14
D208: JP165.8, U70.32
D209: JP165.7, U70.1
D210: JP165.6, U70.2
D211: JP165.5, U70.9
D212: JP165.4, U70.10
D213: JP165.3, U70.11
D214: JP165.2, U70.12
D215: JP165.1, U70.13
D216: JP164.12, U70.14
D+: JP1.USB_P, U1.11
D+1: JP4.USB_P, U6.11
D+2: JP15.USB_P, U9.11
D+3: JP22.USB_P, U12.11
D+4: JP29.USB_P, U15.11
D+5: JP36.USB_P, U18.11
D+6: JP43.USB_P, U21.11
D+7: JP50.USB_P, U24.11
D+8: JP57.USB_P, U27.11
D+9: JP64.USB_P, U30.11
D+10: JP71.USB_P, U33.11
D+11: JP78.USB_P, U36.11
D+12: JP85.USB_P, U39.11
D+13: JP92.USB_P, U42.11
D+14: JP99.USB_P, U45.11
D+15: JP106.USB_P, U48.11
D+16: JP113.USB_P, U51.11
D+17: JP120.USB_P, U54.11
D+18: JP127.USB_P, U57.11
D+19: JP134.USB_P, U60.11
D+20: JP141.USB_P, U63.11
D+21: JP148.USB_P, U66.11
D+22: JP155.USB_P, U69.11
D+23: JP162.USB_P, U72.11
D-: JP1.USB_M, U1.12
D-1: JP4.USB_M, U6.12
D-2: JP15.USB_M, U9.12
D-3: JP22.USB_M, U12.12
D-4: JP29.USB_M, U15.12
D-5: JP36.USB_M, U18.12
D-6: JP43.USB_M, U21.12
D-7: JP50.USB_M, U24.12
D-8: JP57.USB_M, U27.12
D-9: JP64.USB_M, U30.12
D-10: JP71.USB_M, U33.12
D-11: JP78.USB_M, U36.12
D-12: JP85.USB_M, U39.12
D-13: JP92.USB_M, U42.12
D-14: JP99.USB_M, U45.12
D-15: JP106.USB_M, U48.12
D-16: JP113.USB_M, U51.12
D-17: JP120.USB_M, U54.12
D-18: JP127.USB_M, U57.12
D-19: JP134.USB_M, U60.12
D-20: JP141.USB_M, U63.12
D-21: JP148.USB_M, U66.12
D-22: JP155.USB_M, U69.12
D-23: JP162.USB_M, U72.12
DTR: C4.1, Q2.3, R7.1
DTR1: C2.1, Q4.3, R15.1
DTR2: C20.1, Q6.3, R23.1
DTR3: C29.1, Q8.3, R31.1
DTR4: C38.1, Q10.3, R39.1
DTR5: C47.1, Q12.3, R47.1
DTR6: C56.1, Q14.3, R55.1
DTR7: C65.1, Q16.3, R63.1
DTR8: C74.1, Q18.3, R71.1
DTR9: C83.1, Q20.3, R79.1
DTR10: C92.1, Q22.3, R87.1
DTR11: C101.1, Q24.3, R95.1
DTR12: C110.1, Q26.3, R103.1
DTR13: C119.1, Q28.3, R111.1
DTR14: C128.1, Q30.3, R119.1
DTR15: C137.1, Q32.3, R127.1
DTR16: C146.1, Q34.3, R135.1
DTR17: C155.1, Q36.3, R143.1
DTR18: C164.1, Q38.3, R151.1
DTR19: C173.1, Q40.3, R159.1
DTR20: C182.1, Q42.3, R167.1
DTR21: C191.1, Q44.3, R175.1
DTR22: C200.1, Q46.3, R183.1
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

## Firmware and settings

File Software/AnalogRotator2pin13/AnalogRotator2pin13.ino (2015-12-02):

/*
  Blink
  Turns on an LED on for one second, then off for one second, repeatedly.

  Most Arduinos have an on-board LED you can control. On the Uno and
  Leonardo, it is attached to digital pin 13. If you're unsure what
  pin the on-board LED is connected to on your Arduino model, check
  the documentation at http://www.arduino.cc

  This example code is in the public domain.

  modified 8 May 2014
  by Scott Fitzgerald
*/


// the setup function runs once when you press reset or power the board
void setup() {
  // initialize digital pin 13 as an output.
  pinMode(6, OUTPUT);
  pinMode(13, OUTPUT);
  pinMode(A0, INPUT_PULLUP);
  pinMode(A1, INPUT_PULLUP);
  pinMode(A2, INPUT_PULLUP);
  pinMode(A3, INPUT_PULLUP);
  pinMode(A4, INPUT_PULLUP);
  pinMode(A5, INPUT_PULLUP);
  pinMode(A6, INPUT_PULLUP);
  pinMode(A7, INPUT_PULLUP);
}

int iLoop = 14;

// the loop function runs over and over again forever
void loop() {
  if ( iLoop < 22 )
  {
    analogWrite(6, (analogRead(iLoop) >> 2));   // turn the LED on (HIGH is the voltage level)
    delay(1000);              // wait for a second
    digitalWrite(13, LOW);

  }
  else  //expired
  {
    iLoop = 13;
    digitalWrite(13, HIGH);
  }
  iLoop++;
}

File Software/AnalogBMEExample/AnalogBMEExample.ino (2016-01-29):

/****************************************************************
ScrollText.ino
LED Array 8x7 Charlieplex
Shawn Hymel @ SparkFun Electronics
February 3, 2015
https://github.com/sparkfun/LED_Array_8x7_Charlieplex

Scrolls text across the LED array for 10 seconds.

Hardware Connections:

IMPORTANT:  The Charlieplex LED board is designed for 2.0 - 3.3V!
            Higher voltages can damage the LEDs.

 Arduino Pin | Charlieplex Board
 ------------|------------------
      2      |         2
      3      |         3
      4      |         4
      5      |         5
      6      |         6
      7      |         7
      8      |         8
      9      |         9

Resources:
Include Chaplex.h, SparkFun_LED_8x7.h
The Chaplex library can be found at: 
http://playground.arduino.cc/Code/Chaplex

Development environment specifics:
Written in Arduino 1.0.6
Tested with SparkFun BadgerStick (Interactive Badge)

This code is beerware; if you see me (or any other SparkFun 
employee) at the local, and you've found our code helpful, please
buy us a round!

Distributed as-is; no warranty is given.
****************************************************************/

#include <Arduino.h>

// Global variables
#define knobPin A3
#define maxAnalog 3.3

void setup()
{
  Serial.begin(9600);
  Serial.println(F_CPU);
  
}

void loop()
{
  delay(1000);
  Serial.println( ((uint16_t)(((float)analogRead(knobPin)) * (float)5 / maxAnalog ) >> 2) & 0x00FF );
  
}

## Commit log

2015-10-03 getting close to review
    [SparkFun_RedStick.brd, SparkFun_RedStick.sch]
2015-10-03 ready for peer review
    [SparkFun_RedStick.brd, SparkFun_RedStick.sch]
2015-10-06 New FTDI and serial pinout
    [SparkFun_RedStick.brd, SparkFun_RedStick.sch]
2015-10-06 ready for review
    [SparkFun_RedStick.brd, SparkFun_RedStick.sch]
2015-10-06 fixed errors
    [SparkFun_RedStick.brd, SparkFun_RedStick.sch]
2015-10-07 Approved DRCs
    [SparkFun_RedStick.brd]
2015-10-07 proto panel created and cammed
    [SparkFun_RedStick-ProtoPanel-v01.brd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]
2015-10-07 added "route out" removed gerbers
    [SparkFun_RedStick-ProtoPanel-v01.brd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]
2015-10-07 Adding back linked .sch/.brd files
    [SparkFun_RedStick.sch]
2015-12-02 Completed electrical testing
    [powerIO.ods]
2015-12-02 Hardware changes for reds review
    [SparkFun_RedStick.brd, SparkFun_RedStick.sch]
2015-12-07 Docu and design touch up
    [SparkFun_RedStick.brd]
2015-12-10 Getting ready for reds
    [SparkFun_RedStick.brd, SparkFun_RedStick.sch]
2015-12-14 Re-approved DRC, renamed U4
    [SparkFun_RedStick.brd, SparkFun_RedStick.sch]
2015-12-21 created panel v10
    [SparkFun_RedStick-ProtoPanel-v01.brd, SparkFun_RedStick_Panel_v10.brd]

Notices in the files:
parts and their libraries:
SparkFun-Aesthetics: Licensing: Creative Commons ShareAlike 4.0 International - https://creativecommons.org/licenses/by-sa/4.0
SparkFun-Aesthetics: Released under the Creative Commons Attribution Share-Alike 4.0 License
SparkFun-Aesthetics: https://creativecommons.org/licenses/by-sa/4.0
